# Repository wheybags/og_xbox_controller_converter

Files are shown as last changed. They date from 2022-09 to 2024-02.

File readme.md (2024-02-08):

# Xbox controller converter
This repo contains firmware to produce a hardware converter which allows an original xbox controller to present itself as an xbox 360 controller for use with pc games.

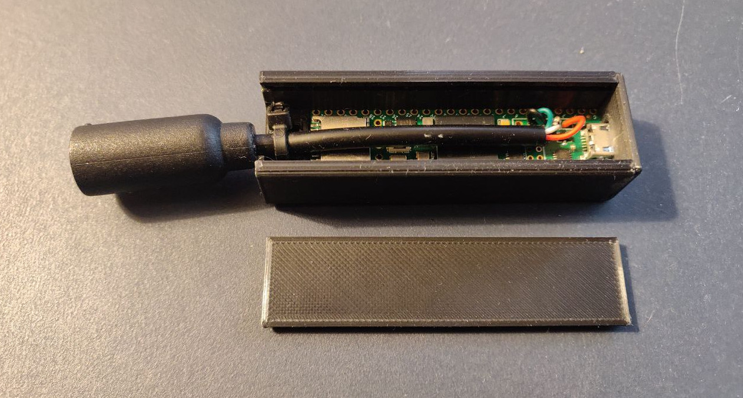
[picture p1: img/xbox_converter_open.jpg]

Case is 3d printed, cad file is `case.FCStd` (freecad format). Glue the front on with epoxy to stop it sliding.
The cable is a cut open xbox controller cable, soldered to the USB host pins on a teensy 4.1, and held down with a cable tie. You can get a sacrificial cable on ebay! Don't destroy an original. You might be able to get this working on some other hardware, but I haven't tried. There's a writeup about this project at http://wheybags.com/blog/xbox.html

# How to build
This is kind of an awful procedure, but in my defence, it's not really my fault. Most of it is just the Arduino ecosystem being a bit unsatisfactory. I used specific versions of Arduino and teensyduino here, it's patches on patches. If you want to use a newer version of anything you're on your own. Installers for the specific versions we need are available in the `dependencies/` folder

- Install Arduino 1.8.19
- Install teensyduino 1.56
- Now we need to install the patches to teensyduino that let us emulate a 360 controller. Copy the `dependencies/ArduinoXInput_Teensy/teensy` folder on top of the `teensy` folder in your Arduino IDE install directory (eg `C:\Program Files (x86)\Arduino\hardware\teensy`)
- Next copy the `dependencies/ArduinoXInput` folder into your Arduino libraries folder (eg `C:\Program Files (x86)\Arduino\libraries\ArduinoXInput`)
- Now open the `xbox.ino` file in the Arduino IDE
- Select the Teensy 4.1 board from the Tools menu
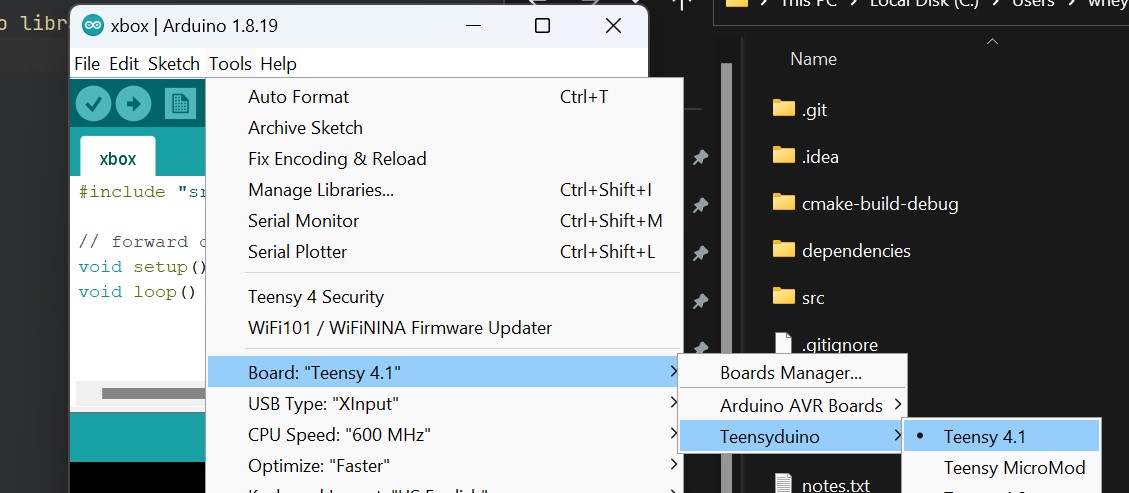
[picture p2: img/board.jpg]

- Set the USB type to XInput
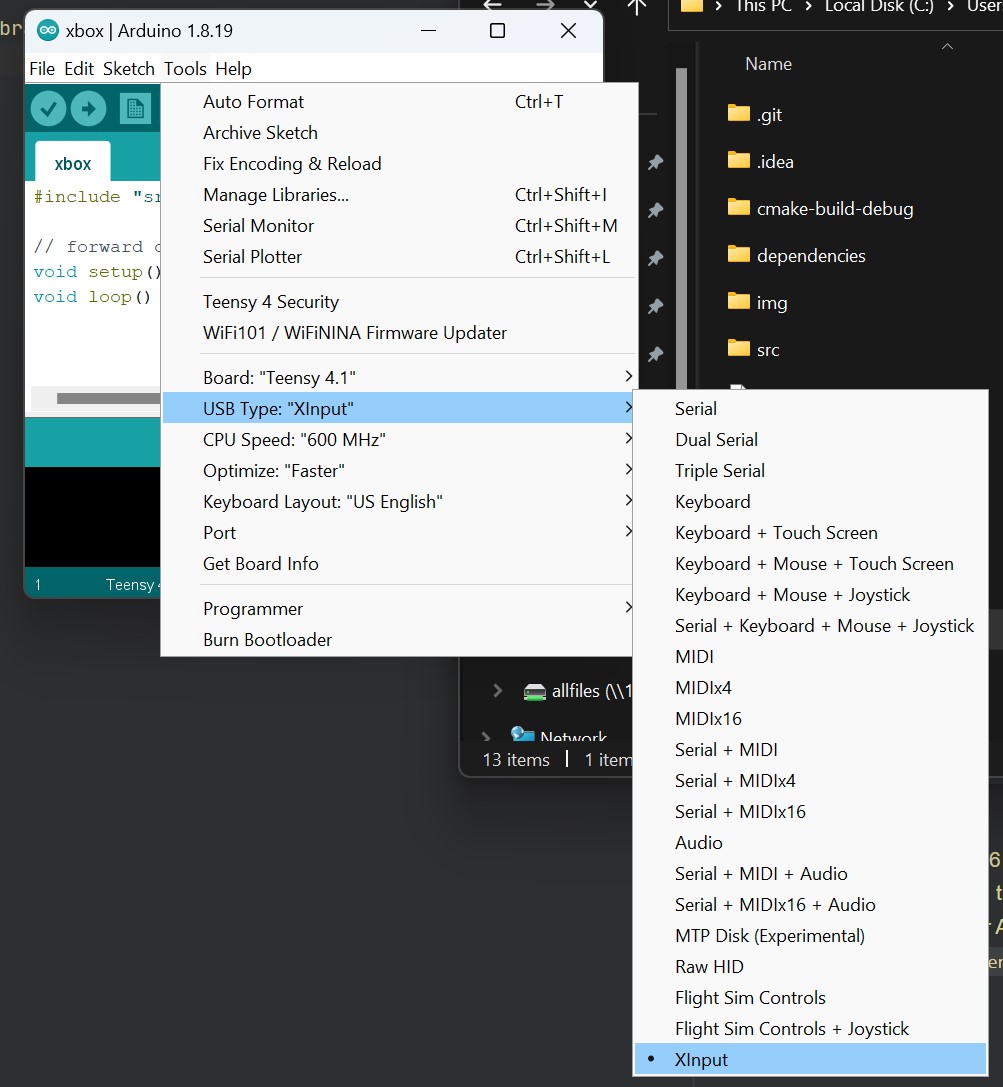
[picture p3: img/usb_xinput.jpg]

- Build the project in arduino IDE. Hopefully it works.

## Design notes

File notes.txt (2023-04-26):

https://github.com/emoose/Xb2XInput/blob/8f4187a23ecd834961151fb68b7a17334820986b/Xb2XInput/XboxController.cpp

https://www.pjrc.com/teensy/beta/usb20.pdf
https://www.intel.com/content/dam/www/public/us/en/documents/technical-specifications/ehci-specification-for-usb.pdf

- appears as a usb hub, wat
- I expected a HID
- ooooh the library is less libusb, more in-tree device driver compilation

- there's this whole ehci thing whoich defines mmio registers for accessing usb controllers

- eventually able to determine the hub device had another device attached, and that was the xbox controller
AAAA  idVendor 45e
AAAA  idProduct 1c
AAAA  deviceClass 9
AAAA  deviceSubClass 0
AAAA  deviceProtocol 0
*** 0 Device Hub1 45e:1c - connected ***
  deviceClass 9
  deviceSubClass 0
  deviceProtocol 0
AAAA  idVendor 45e
AAAA  idProduct 202
AAAA  deviceClass 0
AAAA  deviceSubClass 0
AAAA  deviceProtocol 0

- https://github.com/emoose/Xb2XInput/blob/8f4187a23ecd834961151fb68b7a17334820986b/Xb2XInput/XboxController.cpp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 0x45e 0x202 - "Microsoft Xbox Controller v1 (US)" bingo
- it's really not a HID, hmmm

- whack on the shenzhen io ost
- wow arduino is so bad
- tried platformio https://blog.jetbrains.com/clion/2020/08/arduino-from-hobby-to-prof-p1/ but got random errors
- fake cmakelists.txt just to get clion working, then forward from .ino to cpp immediately

XboxControllerDriver::pipeInCallback
00 14 00 00 00 00 00 00 00 00 00 00 F4 F0 00 00 96 1B 76 F3

vs

XboxControllerDriver::pipeInCallback
00 14 00 00 93 00 00 00 00 00 00 00 F4 F0 00 00 96 1B 76 F3

when holding down A. That's input!!!
TIL

ok, so how to  emulate a 360 controller
xinput

lib for arduino / teensy 3 series : https://github.com/dmadison/ArduinoXInput https://github.com/dmadison/ArduinoXInput_Teensy

ok, lets' port it to teensy 4!
fails enumeration if maxpacketsize is set to 8? dunno lol, it works if I leave it at 64. That took a while to figure out...
can't use endpoint 1 on teensy 4, reserved for future feature, so let's go ahead and remove that reservation... https://github.com/PaulStoffregen/cores/pull/578
    spent like 3 weekends grinding at this, first the enumeration problem, then I couldn't sned anything on endpoint 1
    even found and commented out the `if endpoint < 2` bit
    finally thought to search github issues for endpoint 1, found that pr thank god
        the only thing I was missing was the endpoint config for endpoint 1, so obvious in hindsight

    My favourite part is how the debug console is usb, so I can't print shit
    Just looking at wireshark all day (once I got the device to enumerate, wireshark doesn't show shit if you fail enumeration)
        URB_FUNCTION_SYNC_RESET_PIPE_AND_CLEAR_STALL infinite loop

    when it worked -> look at wireshark oshi sthose look suspiciously like valid packets -> alt tab to gamepad tester FUCK YESSSSS

usbview is great

got rumble packets working after that, it was a bit awkward, but not three bad compared, took only a few hours

solder job immediately fell apart

wait for leaded solder
    it's so much better

played halo
some bugs with rumble
    fixed

pc boots extremely slowly when connected, not sure what the deal is there

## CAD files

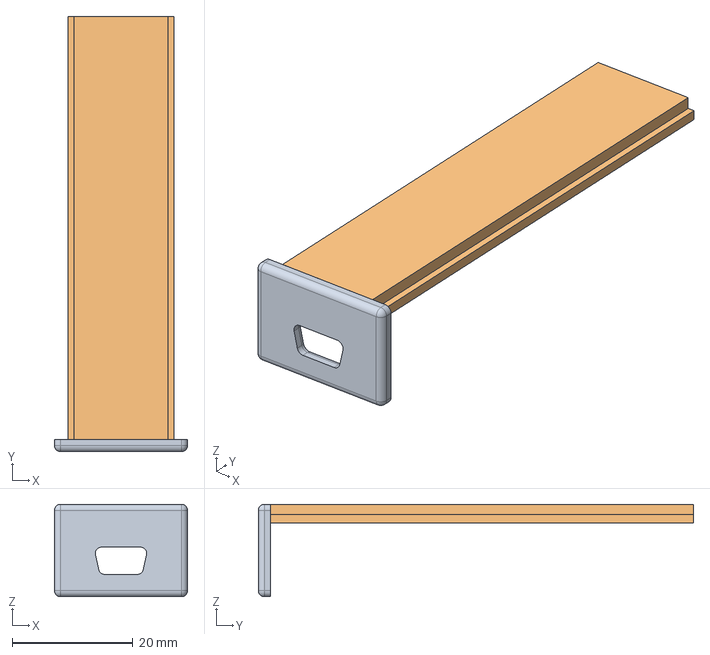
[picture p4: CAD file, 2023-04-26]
case.FCStd
22.0 x 72.0 x 15.3 mm
front_only
slider_only

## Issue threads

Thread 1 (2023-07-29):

S controllers compatibility

Jestzer, 2023-07-29:
Right now, using S controllers works for basic input, but has a number of issues:

- When 2 triggers are pressed at the same time (this may also apply to buttons), the board stops receiving input and requires a disconnect/reconnect to work again.
- No vibration is present.

willsy32, 2024-04-07:
Can confirm no vibration is present on s controllers as well, and when using a vibration test program i had to disconnect/reconnect the device.  I did not have the same issues with analogue triggers or pressing multiple buttons at the same time however.

wheybags, 2024-04-07:
Would be happy to accept a patch for s controller compatibility, but as I don't have one myself I can't test it!

willsy32, 2024-04-08:
> Would be happy to accept a patch for s controller compatibility, but as I don't have one myself I can't test it!

You have a Patreon?  Can send you the funds for one.

sirarcsalot, 2024-04-26:
Am having the same rumble issue with my S controller. It locks up identically to the way the duke controller does in the video.

 Also I am not having the lockup from pressing both triggers either. I played through the entirety of Splinter Cell Pandora Tomorrow on PC with this mod (pc version has no rumble).

Furthermore, it seems any rumble input locks up the controller. Have tried both Dolphin and XEMU emulators and rumble from both locks up the controller. Additionally, native Xinput games on PC lock up the controller with rumble input.

I would be happy to send one of my S controllers as they have already been converted to USB!

Alternatively if you could show how you patched the duke controller rumble I could work on a fix myself.

wheybags, 2024-05-02:
Also it warms my heart that someone else (two people even!) actually made one of these silly things <3

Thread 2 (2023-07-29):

Instruction clarifications

Jestzer, 2023-07-29:
Something that was not included in the instructions is that a port must be specified before compiling the code to the board. This warning appears if you try to verify the code beforehand.

Additionally, it's not made clear which wires connect to which holes on the board (granted, it didn't take too much Googling to find out.) For those who are curious, there are 5 connector holes that are specifically for USB. They are located to the left and under the micro USB port. Turn the board face down. You'll notice the following labels for the holes: GND, GND, D+, D-, +5V. These are holes and corresponding colors to use:

- GND #1: None
- GND #2: Black
- D+: Green
- D-: White
- +5V: Red

The yellow wire is unused.

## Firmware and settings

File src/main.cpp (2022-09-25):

#include <Arduino.h>
#include <USBHost_t36.h>
#include <XInput.h>
#include "XboxControllerDriver.hpp"

USBHost usbHost;
// For some reason my xbox controller actually presents as a hub with a controller device attached.
// Left a second one in here too because why not.
[[maybe_unused]] USBHub hub1(usbHost);
[[maybe_unused]] USBHub hub2(usbHost);
XboxControllerDriver xboxControllerDriver(usbHost);

void mainSetup()
{
  while (!Serial);

  USBHost::begin();

  XInput.begin();
  XInput.setAutoSend(false);
  XInput.setJoystickRange(-32768, 32767);
  XInput.setTriggerRange(0, 255);
}

void mainLoop()
{
  USBHost::Task();

  OGXINPUT_GAMEPAD gamepad = xboxControllerDriver.getLatestReport();
  XInput.setButton(XInputControl::BUTTON_A, gamepad.bAnalogButtons[OGXINPUT_GAMEPAD_A] > 0);
  XInput.setButton(XInputControl::BUTTON_B, gamepad.bAnalogButtons[OGXINPUT_GAMEPAD_B] > 0);
  XInput.setButton(XInputControl::BUTTON_X, gamepad.bAnalogButtons[OGXINPUT_GAMEPAD_X] > 0);
  XInput.setButton(XInputControl::BUTTON_Y, gamepad.bAnalogButtons[OGXINPUT_GAMEPAD_Y] > 0);

  XInput.setJoystick(XInputControl::JOY_LEFT, gamepad.sThumbLX, gamepad.sThumbLY);
  XInput.setJoystick(XInputControl::JOY_RIGHT, gamepad.sThumbRX, gamepad.sThumbRY);

  XInput.setButton(XInputControl::BUTTON_L3, gamepad.wButtons & OGXINPUT_GAMEPAD_LEFT_THUMB);
  XInput.setButton(XInputControl::BUTTON_R3, gamepad.wButtons & OGXINPUT_GAMEPAD_RIGHT_THUMB);

  XInput.setTrigger(XInputControl::TRIGGER_LEFT, gamepad.bAnalogButtons[OGXINPUT_GAMEPAD_LEFT_TRIGGER]);
  XInput.setTrigger(XInputControl::TRIGGER_RIGHT, gamepad.bAnalogButtons[OGXINPUT_GAMEPAD_RIGHT_TRIGGER]);

  XInput.setButton(XInputControl::BUTTON_LB, gamepad.bAnalogButtons[OGXINPUT_GAMEPAD_WHITE] > 0);
  XInput.setButton(XInputControl::BUTTON_RB, gamepad.bAnalogButtons[OGXINPUT_GAMEPAD_BLACK] > 0);

  XInput.setDpad(gamepad.wButtons & OGXINPUT_GAMEPAD_DPAD_UP,
                 gamepad.wButtons & OGXINPUT_GAMEPAD_DPAD_DOWN,
                 gamepad.wButtons & OGXINPUT_GAMEPAD_DPAD_LEFT,
                 gamepad.wButtons & OGXINPUT_GAMEPAD_DPAD_RIGHT,
                 false);

  XInput.setButton(XInputControl::BUTTON_BACK, gamepad.wButtons & OGXINPUT_GAMEPAD_BACK);
  XInput.setButton(XInputControl::BUTTON_START, gamepad.wButtons & OGXINPUT_GAMEPAD_START);

  XInput.setButton(XInputControl::BUTTON_LOGO, (gamepad.wButtons & OGXINPUT_GAMEPAD_BACK) && (gamepad.wButtons & OGXINPUT_GAMEPAD_START));

  auto scale = [](uint8_t x360Rumble) { return uint16_t(x360Rumble * 257);};
  xboxControllerDriver.setRumble(OGXINPUT_RUMBLE{
    .wLeftMotorSpeed = scale(XInput.getRumbleLeft()),
    .wRightMotorSpeed = scale(XInput.getRumbleRight())
  });

  xboxControllerDriver.update();
  XInput.send();
}

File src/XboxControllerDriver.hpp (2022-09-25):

#pragma once
#include <Arduino.h>
#include <USBHost_t36.h>


// https://github.com/emoose/Xb2XInput/blob/8f4187a23ecd834961151fb68b7a17334820986b/Xb2XInput/XboxController.hpp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

// digital button bitmasks
#define OGXINPUT_GAMEPAD_DPAD_UP           0x0001
#define OGXINPUT_GAMEPAD_DPAD_DOWN         0x0002
#define OGXINPUT_GAMEPAD_DPAD_LEFT         0x0004
#define OGXINPUT_GAMEPAD_DPAD_RIGHT        0x0008
#define OGXINPUT_GAMEPAD_START             0x0010
#define OGXINPUT_GAMEPAD_BACK              0x0020
#define OGXINPUT_GAMEPAD_LEFT_THUMB        0x0040
#define OGXINPUT_GAMEPAD_RIGHT_THUMB       0x0080

// analog button indexes
#define OGXINPUT_GAMEPAD_A                0
#define OGXINPUT_GAMEPAD_B                1
#define OGXINPUT_GAMEPAD_X                2
#define OGXINPUT_GAMEPAD_Y                3
#define OGXINPUT_GAMEPAD_BLACK            4
#define OGXINPUT_GAMEPAD_WHITE            5
#define OGXINPUT_GAMEPAD_LEFT_TRIGGER     6
#define OGXINPUT_GAMEPAD_RIGHT_TRIGGER    7

#pragma pack(push, 1)
struct OGXINPUT_RUMBLE
{
  uint16_t wLeftMotorSpeed = 0;
  uint16_t wRightMotorSpeed = 0;
};

struct OGXINPUT_GAMEPAD
{
  uint16_t wButtons;
  uint8_t bAnalogButtons[8];
  int16_t sThumbLX;
  int16_t sThumbLY;
  int16_t sThumbRX;
  int16_t sThumbRY;
};

struct XboxInputReport {
  uint8_t bReportId;
  uint8_t bSize;

  OGXINPUT_GAMEPAD Gamepad;
};

struct XboxOutputReport {
  uint8_t bReportId;
  uint8_t bSize;
  OGXINPUT_RUMBLE Rumble;
};
#pragma pack(pop)

class XboxControllerDriver : public USBDriver {
public:
	XboxControllerDriver(USBHost &host) { init(); }
	XboxControllerDriver(USBHost *host) { init(); }
  virtual ~XboxControllerDriver() = default;

  OGXINPUT_GAMEPAD getLatestReport() const { return reportBuffer.Gamepad; }
  void setRumble(OGXINPUT_RUMBLE rumble, bool force = false);
  void update();

protected:
	bool claim(Device_t *device, int type, const uint8_t *descriptors, uint32_t len) override;
	void disconnect() override;
	void init();

  void control(const Transfer_t *transfer) override;

  static void pipeInCallbackStatic(const Transfer_t* transfer);
  static void pipeOutCallbackStatic(const Transfer_t* transfer);

  void pipeInCallback(const Transfer_t *transfer);
  void pipeOutCallback(const Transfer_t* transfer);

private:
  Pipe_t* pipeIn = nullptr;
  Pipe_t* pipeOut = nullptr;

  XboxInputReport reportBuffer;

  XboxOutputReport rumbleBuffer;
  bool rumbleBufferReady = false;
  unsigned long lastRumblePacketMillis = 0;

private:
	Pipe_t mypipes[3] __attribute__ ((aligned(32)));
	Transfer_t mytransfers[7] __attribute__ ((aligned(32)));
	strbuf_t mystring_bufs[1];
};

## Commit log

2022-07-23 add USBHost_t36 library from Teensyduino v1.56
2022-07-23 start to add an xbox controller driver
2023-04-26 add readme + cad
    [case.FCStd]
